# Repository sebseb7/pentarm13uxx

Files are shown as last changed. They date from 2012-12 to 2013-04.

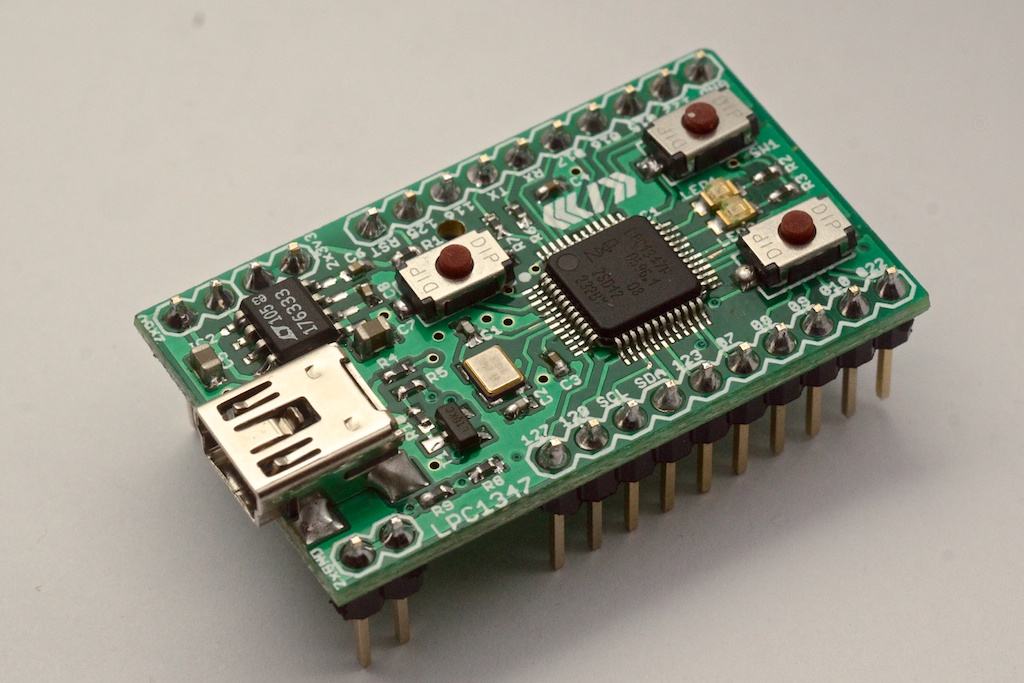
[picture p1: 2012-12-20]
doc/pcb.jpg

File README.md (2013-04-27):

endorse (http://coderwall.com/sebseb7)

pentarm13uxx
============

a small template project (blinking led) for the new lpc1347 (successor of the popular lpc1343)

including Makefile, linker-script and cmsis and microcontroler header files

also includes eagle files for a small breaboardable eval-board

- - -

####lpc1347 features

* 12k sram (was 8k)
* 64k flash (was 32k)
* 4k EEPROM (new)
* 72Mhz
* USART,I2C,2xSPI
* 12Bit ADC (new)
* USB_MSC, USB_HID, USB_CDC and USB_DFU in rom (new)
* usb-bootloader in rom

- - -

price of the eval board: ~$15

- - -

####BOM:

* C1,C2 : 22pF 0402
* C3,C4 : 100nF 0402
* C6,C8 : 10nF 0402
* C5,C7 : 1µF 0805
* R2,R3,R6,R7 : 150R 0402
* R4,R5 : 33R 0402
* R1,R8,R9 : 15k 0402
* R10 : 1k5 0402
* T1 : Si3102DS SOT23 (or other pfet)
* Q1 : 12Mhz MT (farnell: 1842056)
* IC1 : lpc1347 QFP48 (farnell: 2103477)
* IC2 : LT1763CS8-3.3 SOIC8 (farnell: 1273617)
* X1 : Mini USB Connector SMD (farnell: 1125348)
* X2,X3 : Pin-Header 10 Pin
* X4 : Pin Header 2 Pin
* X5 : Pin Header 4 Pin
* LED1,LED2 : Smd LED 0805
* SW1,SW2,RST : MCTAEF-25N (farnell:1605484)

- - -

data sheet  : http://www.nxp.com/documents/data_sheet/LPC1315_16_17_45_46_47.pdf

user manual : http://www.nxp.com/documents/user_manual/UM10524.pdf

toolchain   : https://launchpad.net/gcc-arm-embedded

- - -   
pcb
brd

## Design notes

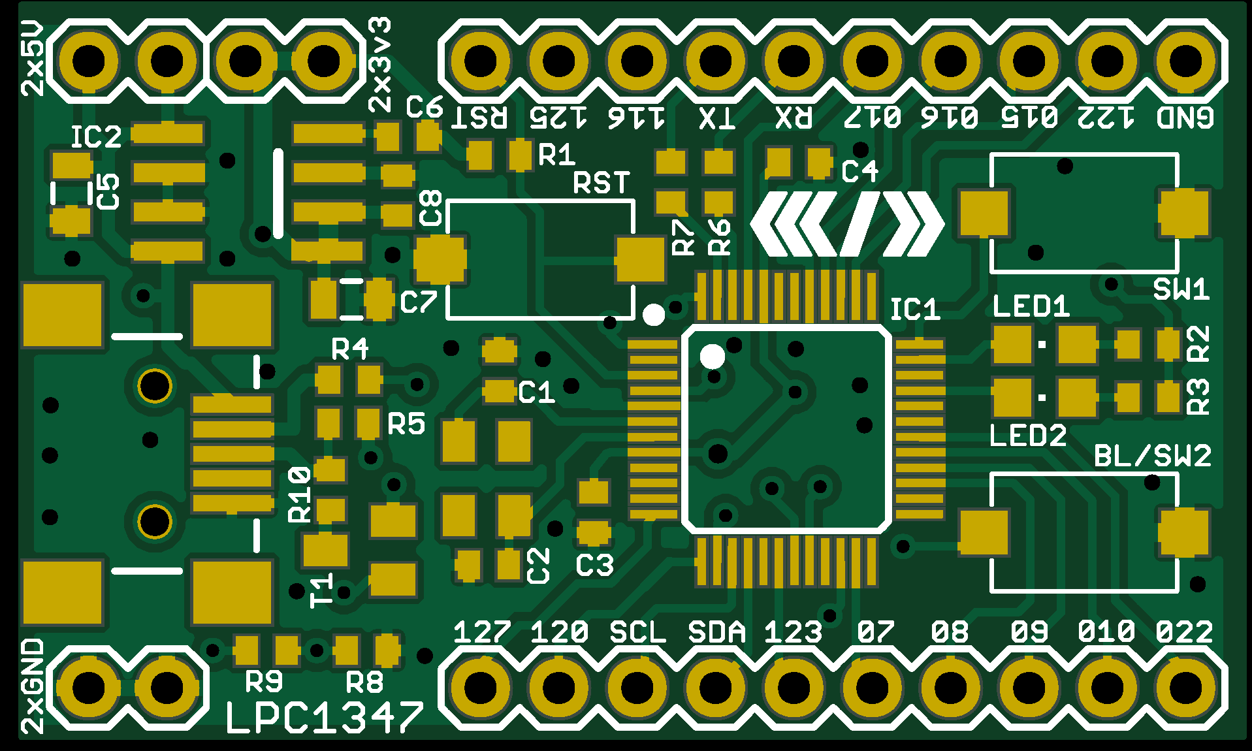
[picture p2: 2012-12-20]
doc/brd.png

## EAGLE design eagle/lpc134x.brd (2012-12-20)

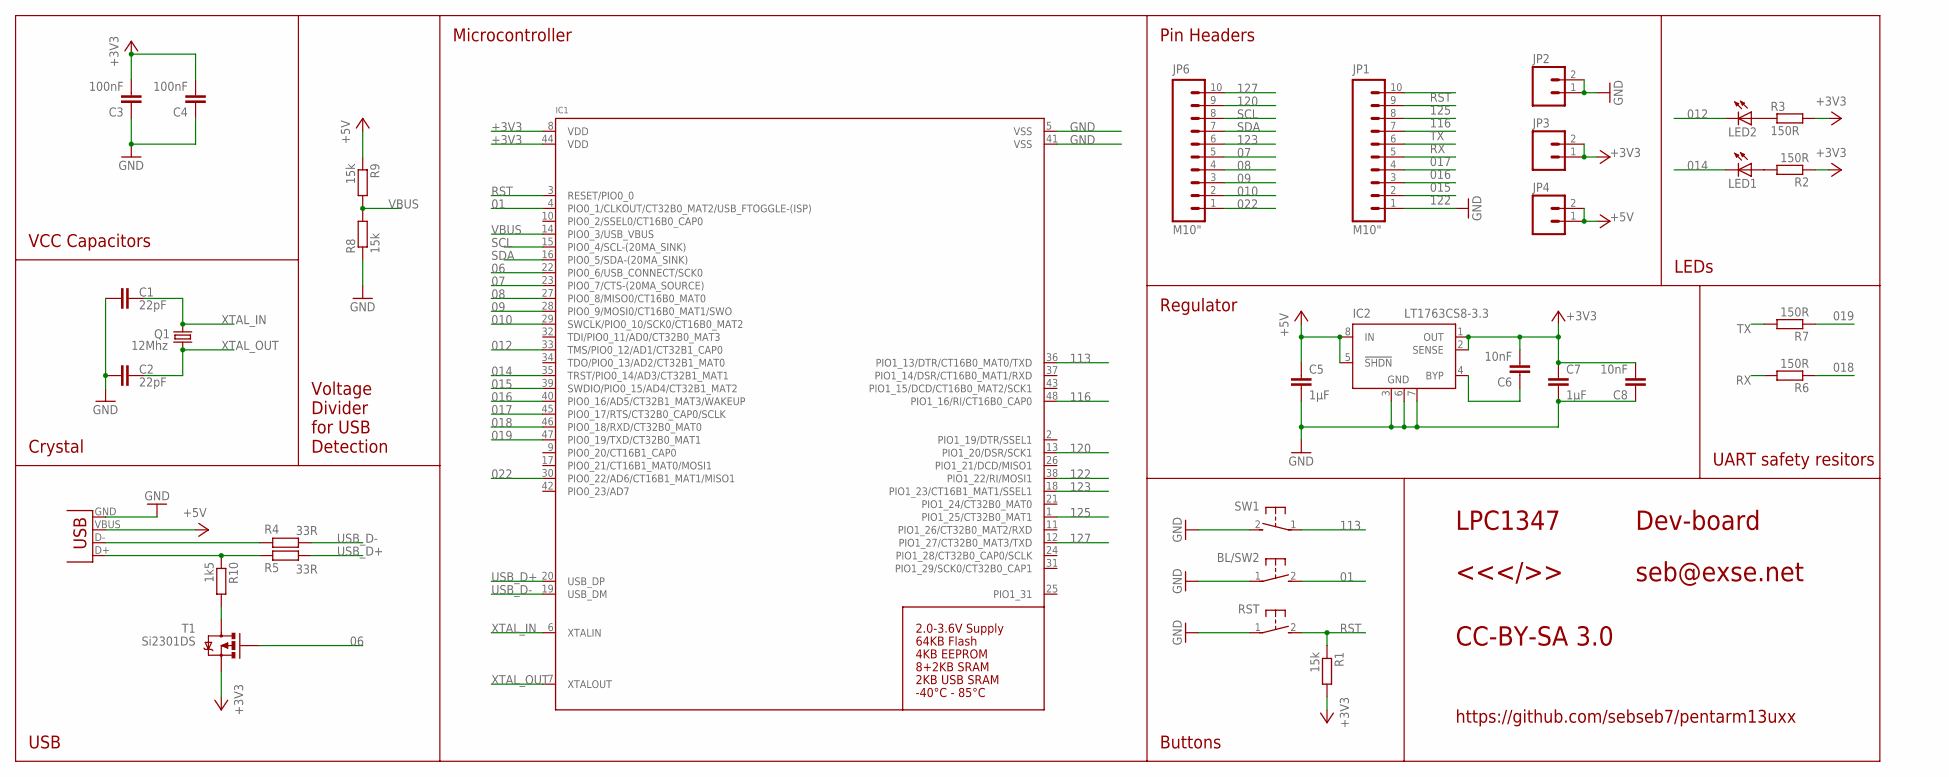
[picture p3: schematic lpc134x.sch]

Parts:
BL/SW2: SWITCH_MCTAEF
C1, C2: 22pF; C0402
C3, C4: 100nF; C0402
C5, C7: 1µF; 0805
C6, C8: 10nF; C0402
IC1: LPC1347_QFP48; LQFP48
IC2: LT1763CS8-3.3; SOIC8
JP1, JP6: M10"; 1X10
JP2, JP3, JP4: M02PTH; 1X02
LED1, LED2: LEDCHIPLED_0805; CHIPLED_0805
Q1: 12Mhz; MT
R1, R8, R9: 15k; R0402
R2, R3, R6, R7: 150R; R0402
R4, R5: 33R; R0402
R10: 1k5; R0402
RST: SWITCH_MCTAEF
SW1: SWITCH_MCTAEF
T1: Si2301DS; SOT23
X2: USB-SMD-NS; USB-MINIB-NOSTOP

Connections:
01: BL/SW2.2, IC1.4 (PIO0_1/CLKOUT/CT32B0_MAT2/USB_FTOGGLE-(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)
06: IC1.22 (PIO0_6/USB_CONNECT/SCK0), T1.1 (G)
07: IC1.23 (PIO0_7/CTS-(20MA_SOURCE)), JP6.5
08: IC1.27 (PIO0_8/MISO0/CT16B0_MAT0), JP6.4
09: IC1.28 (PIO0_9/MOSI0/CT16B0_MAT1/SWO), JP6.3
010: IC1.29 (SWCLK/PIO0_10/SCK0/CT16B0_MAT2), JP6.2
012: IC1.33 (TMS/PIO0_12/AD1/CT32B1_CAP0), LED2.C
014: IC1.35 (TRST/PIO0_14/AD3/CT32B1_MAT1), LED1.C
015: IC1.39 (SWDIO/PIO0_15/AD4/CT32B1_MAT2), JP1.3
016: IC1.40 (PIO0_16/AD5/CT32B1_MAT3/WAKEUP), JP1.4
017: IC1.45 (PIO0_17/RTS/CT32B0_CAP0/SCLK), JP1.5
018: IC1.46 (PIO0_18/RXD/CT32B0_MAT0), R6.1
019: IC1.47 (PIO0_19/TXD/CT32B0_MAT1), R7.1
022: IC1.30 (PIO0_22/AD6/CT16B1_MAT1/MISO1), JP6.1
113: IC1.36 (PIO1_13/DTR/CT16B0_MAT0/TXD), SW1.1
116: IC1.48 (PIO1_16/RI/CT16B0_CAP0), JP1.8
120: IC1.13 (PIO1_20/DSR/SCK1), JP6.9
122: IC1.38 (PIO1_22/RI/MOSI1), JP1.2
123: IC1.18 (PIO1_23/CT16B1_MAT1/SSEL1), JP6.6
125: IC1.1 (PIO1_25/CT32B0_MAT1), JP1.9
127: IC1.12 (PIO1_27/CT32B0_MAT3/TXD), JP6.10
+3V3: C3.2, C4.2, C6.2, C7.1, C8.2, IC1.8 (VDD), IC1.44 (VDD), IC2.1 (OUT), IC2.2 (SENSE), JP3.1, JP3.2, R1.2, R2.1, R3.2, T1.2 (S)
+5V: C5.1, IC2.5 (!SHDN), IC2.8 (IN), JP4.1, JP4.2, R9.1, X2.VBUS
GND: BL/SW2.1, C1.1, C2.1, C3.1, C4.1, C5.2, C7.2, C8.1, IC1.5 (VSS), IC1.41 (VSS), IC2.3 (GND), IC2.6 (GND), IC2.7 (GND), JP1.1, JP2.1, JP2.2, R8.1, RST.1, SW1.2, X2.GND
unnamed: R5.2, R10.1, X2.D+
unnamed: R4.2, X2.D-
unnamed: C6.1, IC2.4 (BYP)
unnamed: LED1.A, R2.2
unnamed: R10.2, T1.3 (D)
unnamed: LED2.A, R3.1
RST: IC1.3 (RESET/PIO0_0), JP1.10, R1.1, RST.2
RX: JP1.6, R6.2
SCL: IC1.15 (PIO0_4/SCL-(20MA_SINK)), JP6.8
SDA: IC1.16 (PIO0_5/SDA-(20MA_SINK)), JP6.7
TX: JP1.7, R7.2
USB_D+: IC1.20 (USB_DP), R5.1
USB_D-: IC1.19 (USB_DM), R4.1
VBUS: IC1.14 (PIO0_3/USB_VBUS), R8.2, R9.2
XTAL_IN: C1.2, IC1.6 (XTALIN), Q1.3 (2)
XTAL_OUT: C2.2, IC1.7 (XTALOUT), Q1.1

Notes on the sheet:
Pin Headers
Regulator
Buttons
LEDs
UART safety resitors
Microcontroller
Voltage Divider for USB Detection
Crystal
VCC Capacitors
USB
CC-BY-SA 3.0
seb@exse.net
<<</>>
LPC1347
Dev-board
https://github.com/sebseb7/pentarm13uxx

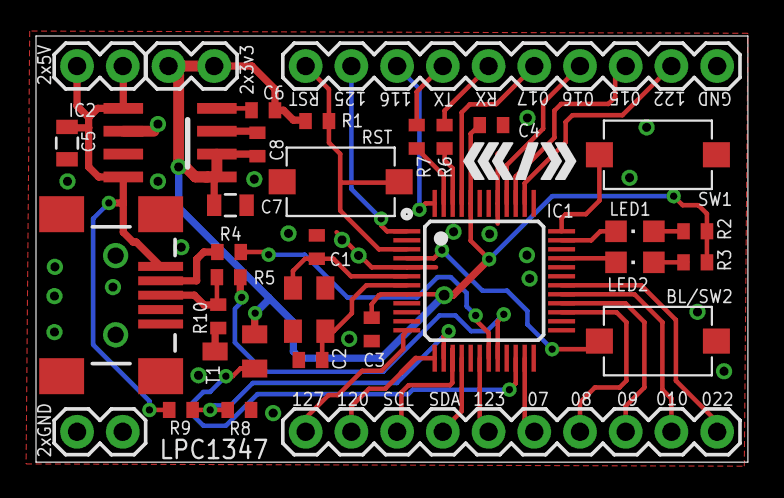
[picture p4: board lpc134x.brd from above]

Board: 2 copper layers, 39.5 x 23.7 mm, 34 parts (0 on the bottom side), 40 nets.

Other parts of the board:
U$2: C3D2_LOGO_SMALL

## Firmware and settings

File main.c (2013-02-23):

#include "main.h"

/*

	data sheet  : http://www.nxp.com/documents/data_sheet/LPC1315_16_17_45_46_47.pdf
	user manual : http://www.nxp.com/documents/user_manual/UM10524.pdf


	led1 : pin 33 (0_12)
	led2 : pin 35 (0_14)

*/
#include <stdio.h>

#include "drivers/usb_cdc.h"
#include "drivers/buttons.h"
#include "drivers/armmath.h"
#include "core/inc/lpc13uxx_timer32.h"

volatile uint32_t msTicks = 0;
static uint16_t buttonsInitialized = 0;
static uint8_t mode  = 0;

void SysTick_Handler(void) {
	msTicks++;

	if(buttonsInitialized)
	{
		buttons_sample();
	}
}

void delay_ms(uint32_t ms) {
	uint32_t now = msTicks;
	while ((msTicks-now) < ms);
}

int main(void) {


	SystemCoreClockUpdate();
	SysTick_Config(SystemCoreClock/1000);

	// clock to GPIO
	LPC_SYSCON->SYSAHBCLKCTRL |= (1<<6);

	// configure the two LEDs PINs as GPIO (they default to jtag)
	LPC_IOCON->TMS_PIO0_12  &= ~0x07;
	LPC_IOCON->TMS_PIO0_12  |= 0x01;
	LPC_IOCON->TRST_PIO0_14  &= ~0x07;
	LPC_IOCON->TRST_PIO0_14  |= 0x01;
	LPC_IOCON->SWCLK_PIO0_10  &= ~0x07;
	LPC_IOCON->SWCLK_PIO0_10  |= 0x01;

	//data direction: output
	LPC_GPIO->DIR[0] |= (1<<10);
	LPC_GPIO->DIR[0] |= (1<<12);
	LPC_GPIO->DIR[0] |= (1<<14);



	//ADC pin 015 ADC4
	LPC_IOCON->SWDIO_PIO0_15 = 0x02;
	LPC_SYSCON->PDRUNCFG &= ~(1 << 4);
	LPC_SYSCON->SYSAHBCLKCTRL |= (1 << 13);
	LPC_ADC->CR = (1<< 4) | (4<< 8) | (1<< 22);

	buttons_init();
	buttonsInitialized=1;




	LPC_GPIO->B0[12] = 1;
	LPC_GPIO->B0[10] = 1;


//	usb_init();

		volatile uint32_t period = 0x15F900; //48Khz PWM frequency

		init_timer32PWM(0, period, MATCH1);
		setMatch_timer32PWM (0, 1, period-72000); // PIO 1.10
		//setMatch_timer32PWM (1, 3, 100); // PIO 1.9
		enable_timer32(0);

	buttons_get_press( KEY_C|KEY_B|KEY_A );


	uint8_t led_counter = 0;

	uint16_t sin1_counter = 0;
	uint16_t sin2_counter = 0;

	while(1)
	{
		led_counter++;
		sin1_counter+=50;
		sin2_counter+=3;

		if(led_counter == 64)
		{
			led_counter = 0;
		}

		if(buttons_get_press( KEY_A|KEY_B|KEY_C ))
		{
			mode ++;
			if(mode == 4)
			{
				mode = 0;
			}
		}
		
		uint32_t pwm=0;
		uint16_t ADC_Data=0;
	
		if(mode == 0)
		{
			if(led_counter < 3)
			{
				LPC_GPIO->B0[12] = 0;
				LPC_GPIO->B0[10] = 1;
			}
			else
			{
				LPC_GPIO->B0[12] = 1;
				LPC_GPIO->B0[10] = 0;
			}
		}

		if(mode == 1)
		{
			LPC_GPIO->B0[12] = 0;
			LPC_GPIO->B0[10] = 1;

		
			LPC_ADC->CR |= (1 << 24);              /* start A/D convert */
			while( (LPC_ADC->GDR & (1 << 31)) == 0 ); /* wait until end of A/D convert */

			LPC_ADC->CR &= 0xF8FFFFFF;      /* stop ADC now (START = 000)*/   

			ADC_Data = ( LPC_ADC->GDR >> 4 ) & 0xFFF;
		
			if(ADC_Data < 100)
			{
				pwm  = 0;
			}
			else
			{
				pwm = 13000 + ((ADC_Data-100) * 2.5f);
			}
		}

		if(mode == 2)
		{
			if(led_counter & 8)
			{
				LPC_GPIO->B0[12] = 0;
				LPC_GPIO->B0[10] = 1;
			}
			else
			{
				LPC_GPIO->B0[12] = 1;
				LPC_GPIO->B0[10] = 0;
			}

			pwm = 13000 + ( (sini(sin1_counter)>>4) * 2.5f);
			LPC_GPIO->B0[14] = 1;
		}
		
		if(mode == 3)
		{
			if(led_counter & 4)
			{
				LPC_GPIO->B0[12] = 0;
				LPC_GPIO->B0[10] = 1;
			}
			else
			{
				LPC_GPIO->B0[12] = 1;
				LPC_GPIO->B0[10] = 0;
			}

			pwm = 13000 + ( (sini(sin2_counter)>>4) * 2.5f);
			
			LPC_GPIO->B0[14] = 0;
		}
	
		setMatch_timer32PWM (0, 1, period-(72000+pwm)); // PIO 1.10
		//setMatch_timer32PWM (0, 1, period-(72000+(ADC_Data*17.578125f))); // PIO 1.10

		char text[200];
		sprintf(text,"%u %u \n",(uint16_t)ADC_Data, (uint16_t)pwm );
		
	//	usb_send_str(text);
				
		LPC_GPIO->NOT[0] = 1<<14;

		delay_ms(40);
	}
}

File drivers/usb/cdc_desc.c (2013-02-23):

/***********************************************************************
* $Id:: cdc_desc.c 211 2011-06-17 21:34:04Z usb06052                          $
*
* Project: USB CDC
*
* Description:
*     USB Communication Device Class User module.
*
***********************************************************************
*   Copyright(C) 2011, NXP Semiconductor
*   All rights reserved.
*
* Software that is described herein is for illustrative purposes only
* which provides customers with programming information regarding the
* products. This software is supplied "AS IS" without any warranties.
* NXP Semiconductors assumes no responsibility or liability for the
* use of the software, conveys no license or title under any patent,
* copyright, or mask work right to the product. NXP Semiconductors
* reserves the right to make changes in the software without
* notification. NXP Semiconductors also make no representation or
* warranty that such application will be suitable for the specified
* use without further testing or modification.
* Permission to use, copy, modify, and distribute this software and its
* documentation is hereby granted, under NXP Semiconductors'
* relevant copyright in the software, without fee, provided that it
* is used in conjunction with NXP Semiconductors microcontrollers.  This
* copyright, permission, and disclaimer notice must appear in all copies of
* this code.
**********************************************************************/
#include <string.h>
#include "mw_usbd.h"
#include "mw_usbd_rom_api.h"
#include "app_usbd_cfg.h"

#if defined (__GNUC__)
 
/* USB Standard Device Descriptor */
__attribute__ ((aligned(4))) const uint8_t VCOM_DeviceDescriptor[] = {
  USB_DEVICE_DESC_SIZE,              /* bLength */
  USB_DEVICE_DESCRIPTOR_TYPE,        /* bDescriptorType */
  WBVAL(0x0200), /* 2.0 */           /* bcdUSB */
  USB_DEVICE_CLASS_COMMUNICATIONS,   /* bDeviceClass CDC*/
  0x00,                              /* bDeviceSubClass */
  0x00,                              /* bDeviceProtocol */
  USB_MAX_PACKET0,                   /* bMaxPacketSize0 */
  WBVAL(0x1FC9),                     /* idVendor */
  //WBVAL(0x000B),                     /* idProduct */
  WBVAL(0x0011),                     /* idProduct */
  WBVAL(0x0100), /* 1.00 */          /* bcdDevice */
  0x01,                              /* iManufacturer */
  0x02,                              /* iProduct */
  0x03,                              /* iSerialNumber */
  0x01                               /* bNumConfigurations: one possible configuration*/
};

/* USB Configuration Descriptor */
/*   All Descriptors (Configuration, Interface, Endpoint, Class, Vendor */
__attribute__ ((aligned(4))) const uint8_t VCOM_ConfigDescriptor[] = {
/* Configuration 1 */
  USB_CONFIGUARTION_DESC_SIZE,       /* bLength */
  USB_CONFIGURATION_DESCRIPTOR_TYPE, /* bDescriptorType */
  WBVAL(                             /* wTotalLength */
    1*USB_CONFIGUARTION_DESC_SIZE +
    1*USB_INTERFACE_DESC_SIZE     +  /* communication interface */
    0x0013                        +  /* CDC functions */
    1*USB_ENDPOINT_DESC_SIZE      +  /* interrupt endpoint */
    1*USB_INTERFACE_DESC_SIZE     +  /* data interface */
    2*USB_ENDPOINT_DESC_SIZE         /* bulk endpoints */
      ),
  0x02,                              /* bNumInterfaces */
  0x01,                              /* bConfigurationValue: 0x01 is used to select this configuration */
  0x00,                              /* iConfiguration: no string to describe this configuration */
  USB_CONFIG_BUS_POWERED /*|*/       /* bmAttributes */
/*USB_CONFIG_REMOTE_WAKEUP*/,
  USB_CONFIG_POWER_MA(100),          /* bMaxPower, device power consumption is 100 mA */
/* Interface 0, Alternate Setting 0, Communication class interface descriptor */
  USB_INTERFACE_DESC_SIZE,           /* bLength */
  USB_INTERFACE_DESCRIPTOR_TYPE,     /* bDescriptorType */
  USB_CDC_CIF_NUM,                   /* bInterfaceNumber: Number of Interface */
  0x00,                              /* bAlternateSetting: Alternate setting */
  0x01,                              /* bNumEndpoints: One endpoint used */
  CDC_COMMUNICATION_INTERFACE_CLASS, /* bInterfaceClass: Communication Interface Class */
  CDC_ABSTRACT_CONTROL_MODEL,        /* bInterfaceSubClass: Abstract Control Model */
  0x00,                              /* bInterfaceProtocol: no protocol used */
  0x04,                              /* iInterface: */
/*Header Functional Descriptor*/
  0x05,                              /* bLength: Endpoint Descriptor size */
  CDC_CS_INTERFACE,                  /* bDescriptorType: CS_INTERFACE */
  CDC_HEADER,                        /* bDescriptorSubtype: Header Func Desc */
  WBVAL(CDC_V1_10), /* 1.10 */       /* bcdCDC */
/*Call Management Functional Descriptor*/
  0x05,                              /* bFunctionLength */
  CDC_CS_INTERFACE,                  /* bDescriptorType: CS_INTERFACE */
  CDC_CALL_MANAGEMENT,               /* bDescriptorSubtype: Call Management Func Desc */
  0x01,                              /* bmCapabilities: device handles call management */
  0x01,                              /* bDataInterface: CDC data IF ID */
/*Abstract Control Management Functional Descriptor*/
  0x04,                              /* bFunctionLength */
  CDC_CS_INTERFACE,                  /* bDescriptorType: CS_INTERFACE */
  CDC_ABSTRACT_CONTROL_MANAGEMENT,   /* bDescriptorSubtype: Abstract Control Management desc */
  0x02,                              /* bmCapabilities: SET_LINE_CODING, GET_LINE_CODING, SET_CONTROL_LINE_STATE supported */
/*Union Functional Descriptor*/
  0x05,                              /* bFunctionLength */
  CDC_CS_INTERFACE,                  /* bDescriptorType: CS_INTERFACE */
  CDC_UNION,                         /* bDescriptorSubtype: Union func desc */
  USB_CDC_CIF_NUM,                   /* bMasterInterface: Communication class interface is master */
  USB_CDC_DIF_NUM,                   /* bSlaveInterface0: Data class interface is slave 0 */
/*Endpoint 1 Descriptor*/            /* event notification (optional) */
  USB_ENDPOINT_DESC_SIZE,            /* bLength */
  USB_ENDPOINT_DESCRIPTOR_TYPE,      /* bDescriptorType */
  USB_CDC_EP_INT_IN,                /* bEndpointAddress */
  USB_ENDPOINT_TYPE_INTERRUPT,       /* bmAttributes */
  WBVAL(0x0010),                     /* wMaxPacketSize */
  0x02,          /* 2ms */           /* bInterval */
/* Interface 1, Alternate Setting 0, Data class interface descriptor*/
  USB_INTERFACE_DESC_SIZE,           /* bLength */
  USB_INTERFACE_DESCRIPTOR_TYPE,     /* bDescriptorType */
  USB_CDC_DIF_NUM,                   /* bInterfaceNumber: Number of Interface */
  0x00,                              /* bAlternateSetting: no alternate setting */
  0x02,                              /* bNumEndpoints: two endpoints used */
  CDC_DATA_INTERFACE_CLASS,          /* bInterfaceClass: Data Interface Class */
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

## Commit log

2012-09-14 pcb image
2012-09-14 eagle files
    [lpc134x.brd, lpc134x.sch]
2012-10-06 drivers for oled & i2c joystick
2012-10-06 added libs and drivers
2012-10-06 not use drivers in blinky-example
2012-10-06 usb_cdc driver
2012-10-06 uncomplete bmp085 driver
2012-10-06 bmp driver demo
2012-10-09 fixed temperature calculation implementation error
    [bmp085.c]
2012-10-09 bmp085 driver completed
2012-10-15 wrong files
    [lpc134x.brd]
2012-12-20 pcb update
    [lpc134x.brd, lpc134x.sch]

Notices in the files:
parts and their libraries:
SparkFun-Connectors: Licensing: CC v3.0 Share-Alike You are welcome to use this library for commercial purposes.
